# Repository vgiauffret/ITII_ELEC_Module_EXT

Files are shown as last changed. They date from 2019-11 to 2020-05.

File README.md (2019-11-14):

# ITII_ELEC_Module_EXT
Notre projet consiste à améliorer une ruche d’abeille en y ajoutant des capteurs pour permettre à un apiculteur d’obtenir différentes informations sur son ruché tel que la température, l’humidité et le poids de la ruche.

Toutes ces améliorations de la ruche ne doivent en aucun cas gêner l’apiculteur dans son travail et doivent permettre à la ruche de rester mobile. Le système doit être autonome.

Nous sommes en charges de créer le module externe de la Ruche. Le but du module externe de la ruche connecté est de gérer, d'enregistrer la visite de l'apiculteur et de transmettre les données relatives à l'entretien des ruches à une gateway. Le module devra fournir une IHM pour permettre à l'apiculteur d'interagir avec le système et de plusieurs capteurs permettant de récupérer les informations désirées.

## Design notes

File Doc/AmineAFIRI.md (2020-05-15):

Liste des taches
==
- Nom : AFIRI Amine
- Module : Module externe

% Accompli | Nom de la taches | Echeance | Notes
---------- | ---------------- | ---------- | --------------:
100 %  | Cahier charges | 08/11/2019 | Etablir le cahier des charges du module externe 
100 %  | Mise en place du répertoire Github | 08/11/2019 | Création du repository + ajout du cahier des charge + les fichiers taches
100 %  |Recherche| 29/11/2019 | Lecture de la Datasheet de l'ESP32 + Ecran LCD
100    |cablage FTDI232 et ESP32| 29/11/2019 | cablâge des modules pour compilation 
50 %   |Configuration de l'écran LCD| 29/11/2019 | code de test pour afficher des caractères à l'écran
50 %   |Recherche | 13/12/2019 | Recherche sur le ESP3266 + Ecran LCD SSD1306
80 %   |Configuration de l'écran LCD| 13/12/2019 | L'écran s'allume mais probleme de calibrage
100 %  |Reinstallation du noyau Linux| 17/01/2020 | Probleme d'ecran apres mauvaise manipulation
70 %   |Recherche | 17/01/2020 | Recherche sur le ESP3266 + Ecran LCD SSD1306
100 %  |Configuration de l'écran LCD| 17/01/2020 | L'écran s'allume est on peut afficher differentes chaines de caracteres
100 %  |Recherche| 20/01/2020 | Lecture de la Datasheet de du capteur de température DHT22
100 %  |cablage| 20/01/2020 | cablâge du capteur DHT22 pour test 
10 %   |Codage| 20/01/2020 | Elaboration d'un programme qui récupère les données du capteur DHT22
0 %  |Absence| 24/01/2020 | Injustifié (Pour raison personnelle)
0 %  |Absence| 07/02/2020 | Maladie
0 %  |Absence| 08/02/2020 | Maladie
100 %  |Codage| 14/02/2020 | Mise en marche d'un programme qui récupère les données du capteur DHT22
70 %  |Configuration de la balance| 14/02/2020 | Autocalibration de la balance sans intervention de l'utilisateur
70 %  |Configuration de la balance| 20/03/2020 | Autocalibration de la balance sans intervention de l'utilisateur
100 %  |Configuration de la balance | 17/04/2020 | Test écriture et lecture de l'EEPROM
70 %  |Configuration de la balance| 17/04/2020 | Autocalibration de la balance sans intervention de l'utilisateur + Enregistrement des données dans l'EEPROM
100 %  |Configuration de la balance | 22/04/2020 |  Autocalibration de la balance sans intervention de l'utilisateur + Enregistrement des données dans l'EEPROM
60 %  | Recherche Composants | 22/04/2020 | Choix et comparaisons des compossants chez Farnell et RS

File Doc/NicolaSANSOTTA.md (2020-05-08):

Liste des taches
==
- Nom : SANSOTTA Nicola
- Module : Module externe

% Accompli | Nom de la taches | Echeance | Notes
---------- | ---------------- | ---------- | --------------:
100 %  | Cahier charges | 08/11/2019 | Etablir le cahier des charges du modules externes 
100 %  | Diagramme de Gant | 08/11/2019 | Planification des tâches 
100 %  |cablage FTDI232 et ESP32| 29/11/2019 | cablâge des modules pour compilation 
50 %   |configuration de la balance| 29/11/2019 | code de test pour récupérer les valeurs depuis le module NAU7802
100 %  |configuration de la balance| 13/12/2019 | code de test pour récupérer les valeurs depuis le module NAU7802
probléme     |configuration de la balance| 13/12/2019 | Probléme de compilation depuis la plateforme Arduino vers l'ESP3266
25 %   |configuration de la balance| 13/12/2019 | Convertions des valeurs en unité de masse
35 %   |configuration de la balance| 10/01/2020 | Convertions des valeurs en unité de masse
5 %    |Implémentation de la carte| 10/01/2020 | Cablage NAU7802 seul
20 %    |Implémentation de la carte| 11/01/2020 | Cablage des 2 NAU7802 et des différents connecteurs sur Schematic
40 %    |Implémentation de la carte| 20/01/2020 | Cablage et test sur platine des 2 voyant lumineux
50 %    |Implémentation de la carte| 20/01/2020 | Cablage et test des 2 pont diviseur pour messurer la tension d'alimentation et de la baterie
55 %    |Implémentation de la carte| 20/01/2020 | Atribution des pins utilisée sur L'ESP32
65 %    |Implémentation de la carte| 24/01/2020 | Cablage du capteur de température DHT et de la LDR
modification    |Implémentation de la carte| 24/01/2020 | Changement de pin concernant la tension d'entrée du pont diviseur pour messurer la baterie
100 %    |Présentation module externe| 08/02/2020 | 
100 %    |Implémentation de la carte| 14/02/2020 | Finalisation des différents câblage sur le schematic
20 %    |Routgae PCB| 20/03/2020 | Début du routage de la carte module externe ESP_Rucher
100 %    |Routgae PCB| 17/04/2020 | Finalisation de la carte module externe ESP_Rucher
60 %    |Recherche Composants| 22/04/2020 | Choix et comparaisons des compossants chez Farnell et RS

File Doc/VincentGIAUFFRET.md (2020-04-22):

Liste des taches
==
- Nom : GIAUFFRET Vincent
- Module : Module externe

% Accompli | Nom de la taches | Echeance | Notes
---------- | ---------------- | ---------- | --------------:
100 %  |Cahier charges | 08/11/2019 | Etablir le cahier des charges du modules externes 
100 %  |Mise en place répertoire Github | 08/11/2019 | Création du repository + ajout du cahier des charge + les fichiers taches
10 %   |Recherche | 25/11/2019 | Recherche sur le ESP3266 + Ecran LCD SSD1306
100 %  |Cablage FTDI232 et ESP32| 29/11/2019 | cablâge des modules pour compilation 
50 %   |Configuration de l'écran LCD| 29/11/2019 | code de test pour afficher des caractères à l'écran
50 %   |Recherche | 13/12/2019 | Recherche sur le ESP3266 + Ecran LCD SSD1306
80 %   |Configuration de l'écran LCD| 13/12/2019 | L'écran s'allume mais probleme de calibrage
100 %  |Reinstallation du noyau Linux| 17/01/2020 | Probleme d'ecran apres mauvaise manipulation
70 %   |Recherche | 17/01/2020 | Recherche sur le ESP3266 + Ecran LCD SSD1306
100 %  |Configuration de l'écran LCD| 17/01/2020 | L'écran s'allume est on peut afficher differentes chaines de caracteres
100 %  |Mesure Batterie et Alimentation | 20/01/2020 | Pont diviseur pour la mesure de la batterie et de l'alimentation
100 %  |LED Red & Green | 20/01/2020 | Ajout des deux LED et code pour les alimenter
100 %  |Recherche | 17/01/2020 | Recherche sur le ESP3266 + Ecran LCD SSD1306
50 %   |Configuration de l'écran LCD| 20/01/2020 | Modification de l'I2C pour le controler
100 %  |Configuration du module LoRa| 24/01/2020 | Envoyer un message et lire les messages recu
100 %  |Configuration de l'écran LCD| 24/01/2020 | Modification de l'I2C pour le controler
100 %  |Configuration de la photoresistance| 24/01/2020 | Lire la valeur de la luminosité
100 %  |Présentation | 07/02/2020 | Powerpoint de présentation
100 %  |Présentation | 08/02/2020 | Présentation
5 %    |Assemblage Code | 14/02/2020 | Réveil du systéme avec appuie sur le bouton next
10 %   |Assemblage Code | 14/02/2020 | Défilement du menu avec le bouton next
25 %   |Assemblage Code | 14/02/2020 | Ajout du bouton validation
100 %  |Test Eeprom Code | 17/04/2020 | Ecrire et lire dans l'eeprom
30 %   |Balance Code | 17/04/2020 | Proceder au mesure de poids
100 %  |Balance Code | 22/04/2020 | Mesure de poid + ajout code a l'init de l'eeprom
25 %   |Assemblage Code | 22/02/2020 | Ajout du bouton validation

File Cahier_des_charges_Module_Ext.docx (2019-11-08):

Cahier des charges

Module externe ruche connectée

Le but du module externe de la ruche connecté est de gérer, d'enregistrer la visite de l'apiculteur et de transmettre les données relatives à l'entretien des ruches à une gateway. Le module devra fournir une IHM pour permettre à l'apiculteur d'interagir avec le système et de plusieurs capteurs permettant de récupérer les informations désirées.

Les exigences du système sont les suivantes :

1 : Mesurer l’hygrométrie grâce au capteur HDC1080

2 : Mesurer le poids de la ruche grâce à la balance NUA7802

3 : Relever la température de la jauge de contrainte

4 : Gérer les dérives du capteur de force en utilisant les capteurs hygrométriques et de température

5 : Mettre à jour les valeurs mesurées toutes les 15 minutes

6 : Récupérer les mesures sur l’ESP3266

7 : Pouvoir interagir avec l’afficheur via 2 boutons poussoir

8 : Afficher le menu sur l’afficheur LCD SSD1306 qui sera composé des actions suivantes :

- Visite
- Sleep
- Sirop 50/50
- Sirop 70/30
- Candy
- Mesure seule

9 : Afficher le déroulement du processus de visite sur l’afficheur LCD

10 : Transmettre une trame résumant les actions de la visite

11 : Utiliser le RFM95 pour transmettre les trames (LoRa)

Schéma récapitulatif du système :

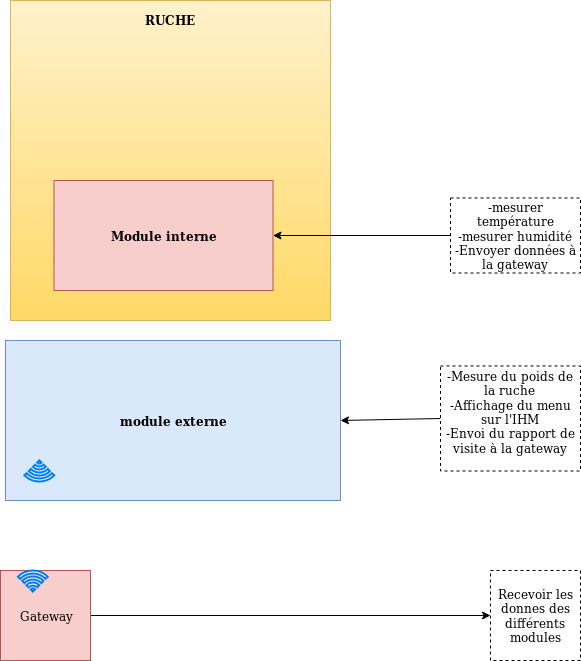
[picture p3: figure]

Le module externe est représenté par les éléments suivants :

Carte avec ESP32µc

+ Capteur Hygro (humidité)

+ 2 BP

Envoi donnée via RFM92

Communication LoRa

Balance NUA7802

Afficheur SSD1306

Annexe

Carte :

Intégration du µC ESP32

Insérer pont de Weaston qui permet d’intégrer la balance NUA7802 et de l’adapter en fonction du nombre de jauges 1, 2 ou 4 pour mesurer le poids de la ruche

1 jauge = 1 pont de Weaston avec 1 ADC NAU7802 (1 entrée utile)
2 jauges = 1 pont de Weaston avec 1 ADC NAU7802 (2 entrée utile)
4 jauges = 2 ponts de Weaston avec 2 ADC NAU7802 (2 entrée utile)

Insérer connecteur de l’afficheur SSD1306
Récupération du signal fournis par la balance avec CAN HX711 établir la connexion
Programmation du µC ESP32

Communication LoRa RFM95 :

Lecture des données (état des capteurs) de la part du système toutes les 15 min.

But => Transmettre une Trame qui contient valeur de masse et hygrométrie et action effectué par le manipulateur de la Ruche.

Gateway

TRAME

Code affichage

Carte vers ESP32

Afficheur

Afficheur :

Programmation avec la plateforme Arduino C++

Réveil du système avec BP et lecture des données (état des capteur)

Gestion du Menu (Sélection Visite ou Rien de la part du propriétaire de la Ruche)

Si Visite sélectionné alors enregistrement dans la table Viste (Envoie d’un TRAME)

Puis déroulement du processus :

But => Afficher la gestion des actions sur l’afficheur SSD1306 et validé que l’action est bien effectuée

Etape 1 : Mesure masse + Envoi donnée dans Trame vers Gateway + Afficher sur l’afficheur

Etape 2 : Accusé de réception

Etape 3 : Sleep pendant 15 ou 30 min à définir

Etape 4 : Afficher Sirop 50 / 50

Etape 5 : Validation Sirop 50 / 50

Etape 6 : Nouvelle mesure de masse (calcul de la différence pour obtenir la masse de sirop) + Envoi donnée dans Trame vers Gateway + Afficher sur l’afficheur

Nicola Sansotta Projet Electronique Ruche Malik Bedoui Vincent Giaufret Amine Afiri

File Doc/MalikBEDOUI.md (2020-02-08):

Liste des taches
==
- Nom : BEDOUI Malik 
- Module : Module externe

% Accompli | Nom de la taches | Echeance | Notes
---------- | ---------------- | ---------- | --------------:
100 %  | Cahier charges | 08/11/2019 | Etablir le cahier des charges du modules externes 
100 %   | Diagramme de Gant | 08/11/2019 | Planification des tâches 
100 %   |cablage FTDI232 et ESP32| 29/11/2019 | cablâge des modules pour compilation 
50 %   |configuration de la balance| 29/11/2019 | code de test pour récupérer les valeurs depuis le module NAU7802
50%    |Configuration de la balance| 13/12/2019 | problème de compilation sur l'esp ce qui nous a retardé
60%    |Configuration de la balance| 10/01/2020 | détermination de l'équation permettant d'avoir une valeur correspondant à un poid en kg.
70%    |Configuration de la balance| 17/01/2020 | autocalibration de la balance sans intervention de l'utilisateur.
70%    |Configuration de la balance| 20/01/2020 | Travail sur balance + cablage module lora.
70%    |Configuration de la balance + Lora| 17/01/2020 | autocalibration de la balance sans intervention de l'utilisateur.
70%    |Module Lora| 17/01/2020 | Envoi et reception de message avec Lora et affichage des bytes reçues sur LCD
100%    |Présentation module externe| 08/02/2020 |

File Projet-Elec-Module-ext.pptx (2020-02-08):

## Projet Electronique Ruche Connectée

Module Externe
Afiri / Bedoui / Giauffret / Sansotta

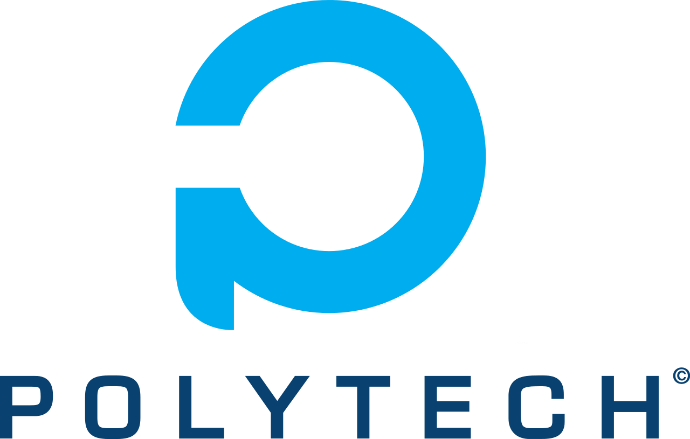
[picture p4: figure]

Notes: Vincent

## Contexte

Actuellement
Des améliorations en vue
Un projet commun avec toute la classe
Le module externe

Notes: Vincent

Depuis 2017 le projet de ruches connectées est lancé

Et notre objectif est d’ajouter des fonctionnalités pour améliorer et faciliter sa

S’interfacer avec les autres groupes, pour réussir a échanger des informations. Cette présentation sera même utile a connaitre les besoin de chaque groupe concernant les

Dans le cadre de la gestion de la ruche, le module externe permet de suivre et d’enregistrer l’état global de la ruche (température,hygrométrie,poids)

## Sommaire

- Vue d’ensemble Module Externe
- Mesures interne
- Communication
- IHM
- Autres fonctionnalités
- Prototypage carte module externe
- Implémentation carte module externe

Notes: Sansotta

## Vue d’ensemble Module Externe

Balance NUA7802

Capteur hygrométrique et de température

Capteur Luminosité

Carte avec ESP32µc

Envoi de données via RFM95
Communication LoRa

Afficheur SSD1306

LED

Boutons capacitifs

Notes: Sansotta

## Mesures internes

Balance
Luminosité
Température
Hygrométrie

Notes: Malik

Balance : vérifier poids du sirop injecté
système d’antivol
compter nombre d’abeille

Luminosité pour réduire le nombre de données envoyé durant la nuit

Température : palier les dérives du capteur de force de la balance(pas sûr qu’on va l’utiiliser)

Hygrométrie pour conservation du miel

## Communication

Réseau LoRa
Envoi des mesures internes

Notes: Malik

## IHM

Interface Homme Machine
Afficheur SSD1306
2 Voyants lumineux
2 boutons capacitifs

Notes: Vincent

## Autres fonctionnalités

Batterie
Alimentation

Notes: Vincent

## Prototypage carte module externe

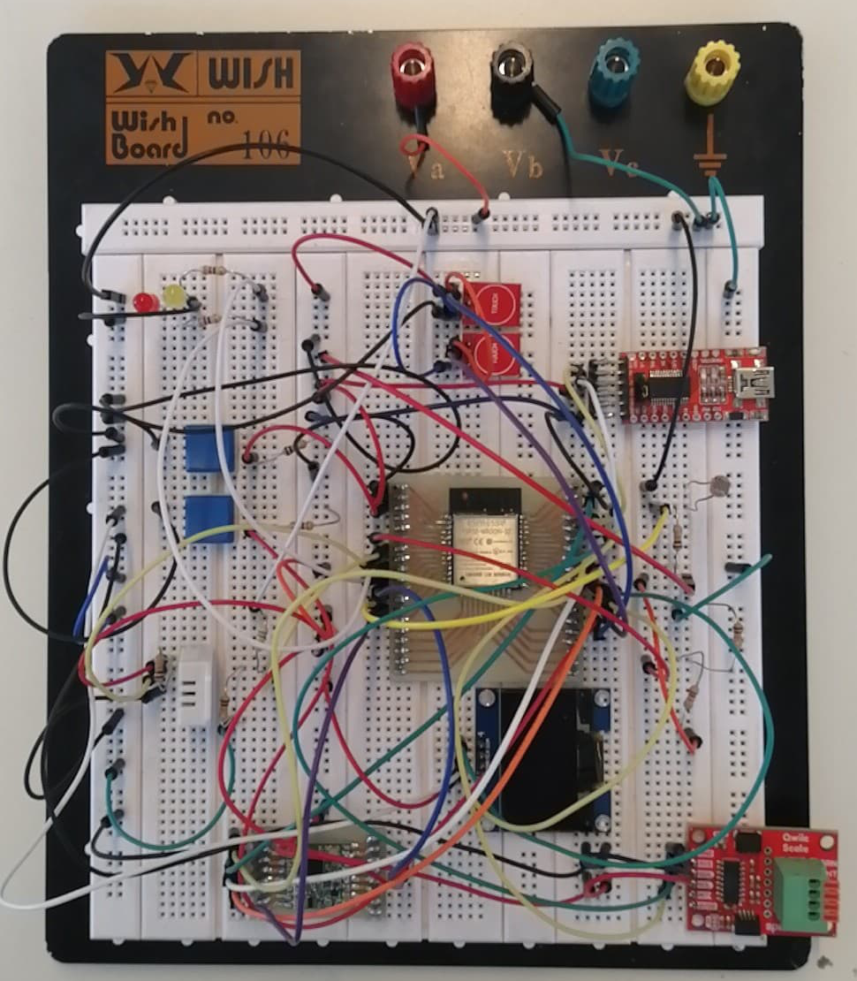
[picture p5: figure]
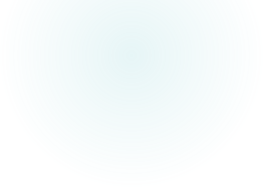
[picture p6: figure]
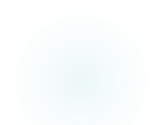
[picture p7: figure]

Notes: Sansotta

## Implémentation

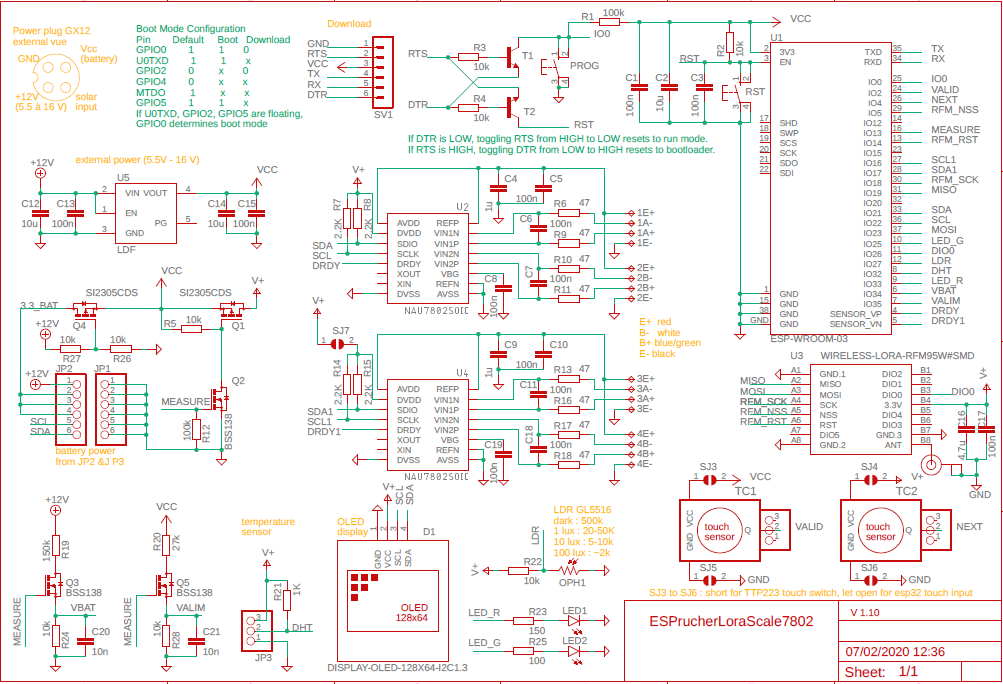
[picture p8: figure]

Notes: Sansotta

## Partage du code

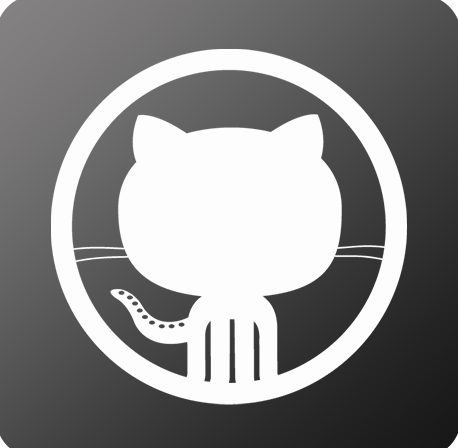
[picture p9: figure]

- Github
- Tableau des tâches et progression

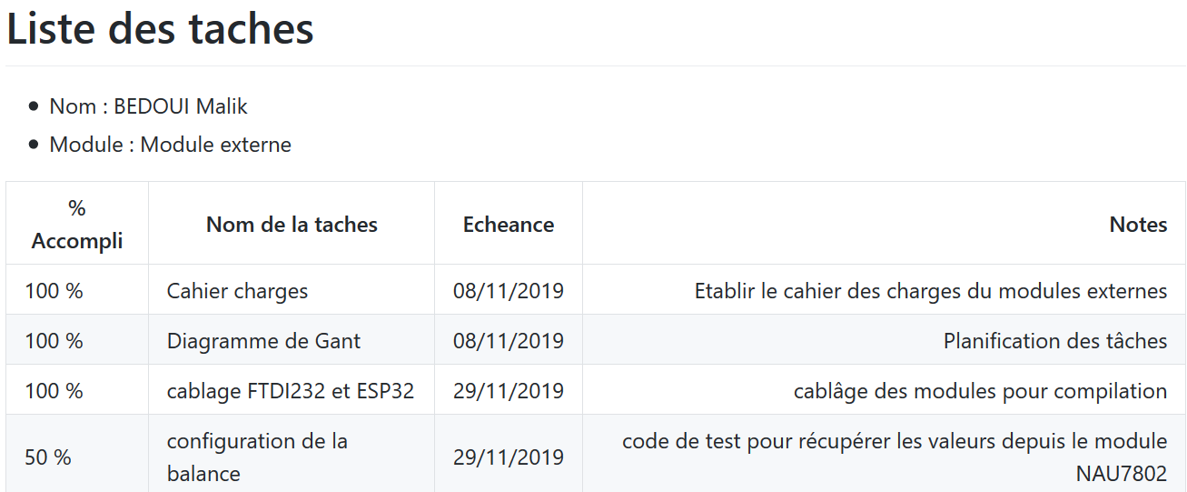
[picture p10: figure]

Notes: Malik

## Conclusion

Tâches | Accomplissement | Commentaires
Mesure de l’hygrométrie | ✔
Mesure de la température | ✔
Mise en place de l’IHM | ✔
Envoi de la trame en LoRa | ✔
Mesure de la luminosité | ✔
Alignement avec les autres groupes | X | Mettre en place un protocole pour la trame à envoyer
Assemblage de toutes les fonctionnalités | X | Intégration de toutes les fonctionnalités dans le programme final
Réalisation de la carte | X | Design du PCB à réaliser
Mesure du poids | X | En cours

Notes: Malik

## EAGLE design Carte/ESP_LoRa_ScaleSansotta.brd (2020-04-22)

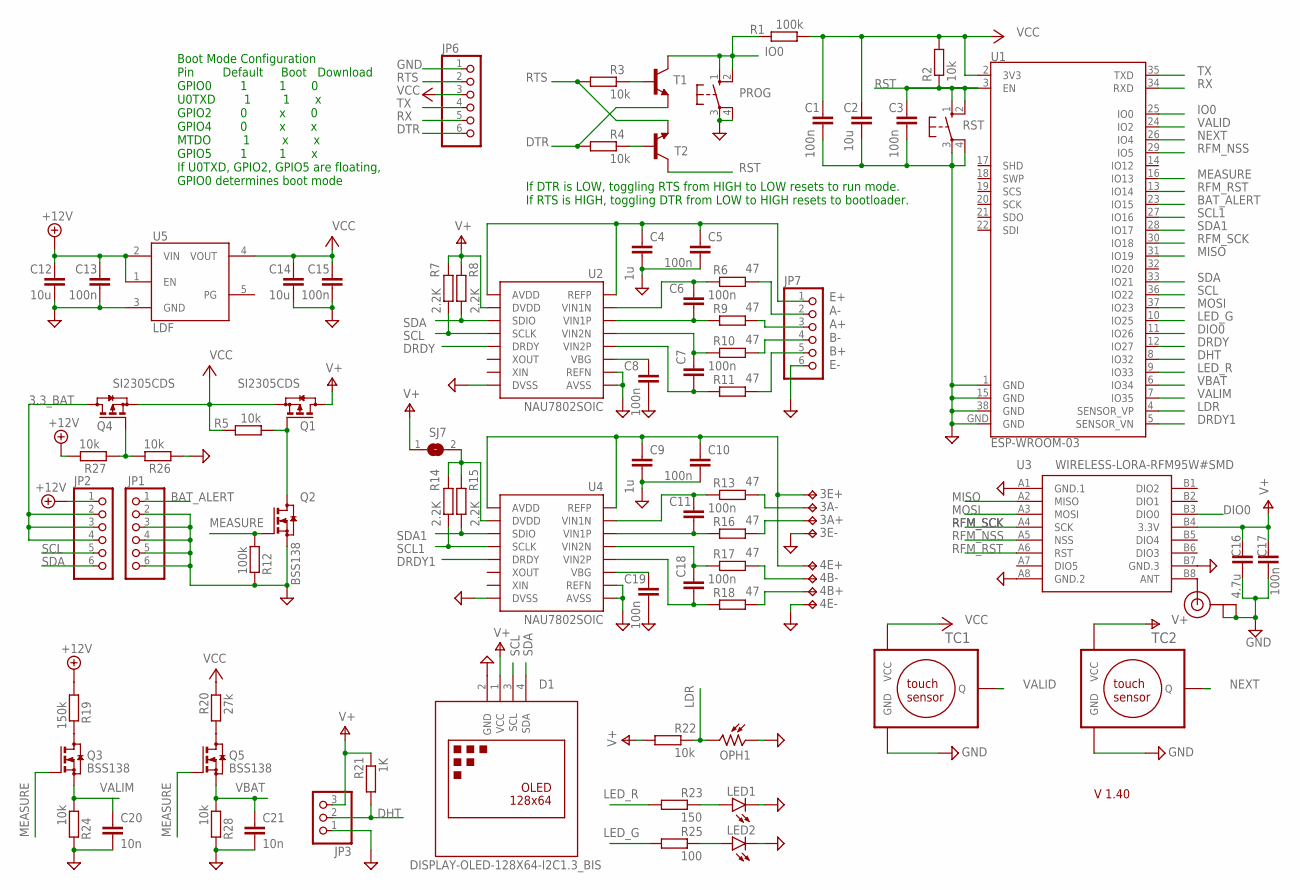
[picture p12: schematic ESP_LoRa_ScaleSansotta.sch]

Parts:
3A+, 3A-, 3E+, 3E-, 4B+, 4B-, 4E+, 4E-: TPTP17SQ; TP17SQ
C1, C3, C5, C6, C7, C8, C10, C11, C13, C15, C17, C18, C19: 100n; C1206
C2, C12, C14: 10u; C1210
C4, C9: 1u; C1210
C16: 4.7u; C1210
C20, C21: 10n; C1206
D1: DISPLAY-OLED-128X64-I2C1.3_BIS; DISPLAY-OLED-128X64-1.3-I2C_BIS
J1: U.FL
JP1, JP2, JP6, JP7: PINHD-1X6; 1X06
JP3: PINHD-1X3; 1X03
LED1, LED2: LEDSMT1206; 1206
OPH1: VT93N2; VT900
PROG: 10-XX; B3F-10XX
Q1, Q4: SI2305CDS; SOT23
Q2, Q3, Q5: BSS138; SOT23
R1, R12: 100k; R1206
R2, R3, R4, R5, R22, R24, R26, R27, R28: 10k; R1206
R6, R9, R10, R11, R13, R16, R17, R18: 47; R1206
R7, R8, R14, R15: 2.2K; R1206
R19: 150k; R1206
R20: 27k; R1206
R21: 1K; R1206
R23: 150; R1206
R25: 100; R1206
RST: 10-XX; B3F-10XX
SJ7: SJ
T1, T2: MMBT2222ALT1-NPN-SOT23-BEC; SOT23-BEC
TC1, TC2: TTP223R_H; TTP233RED_H
U1: ESP-WROOM-03
U2, U4: NAU7802SOIC; SO16
U3: WIRELESS-LORA-RFM95W#SMD
U5: LDF3.3; PPAK

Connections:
3.3_BAT: JP2.2, JP2.3, JP2.4, Q4.3 (D)
+12V: C12.1, C13.1, JP2.1, R19.1, R27.2, U5.1 (EN), U5.2 (VIN)
BAT_ALERT: JP1.1, U1.23 (IO15)
DHT: JP3.2, R21.1, U1.8 (IO32)
DIO0: U1.11 (IO26), U3.B3 (DIO0)
DRDY: U1.12 (IO27), U2.12 (DRDY)
DRDY1: U1.5 (SENSOR_VN), U4.12 (DRDY)
DTR: JP6.6, R4.1, T1.E
GND: 3E-.TP, 4E-.TP, C1.2, C2.2, C3.2, C4.2, C5.2, C8.2, C9.2, C10.2, C12.2, C13.2, C14.2, C15.2, C16.2, C17.2, C19.2, C20.2, C21.2, D1.2 (GND), J1.1 (GND), J1.2 (GND), JP1.2, JP1.3, JP1.4, JP1.5, JP1.6, JP3.1, JP6.1, JP7.6, LED1.C, LED2.C, OPH1.1, PROG.3, PROG.4 (P1), Q2.2 (S), R12.2, R24.2, R26.1, R28.2, RST.3, RST.4 (P1), TC1.P$3 (GND), TC2.P$3 (GND), U1.1 (GND), U1.15 (GND), U1.38 (GND), U1.GND, U2.7 (REFN), U2.8 (AVSS), U2.9 (DVSS), U3.A1 (GND.1), U3.A8 (GND.2), U3.B7 (GND.3), U4.7 (REFN), U4.8 (AVSS), U4.9 (DVSS), U5.3 (GND)
IO0: PROG.1 (S), PROG.2 (S1), R1.2, T1.C, U1.25 (IO0)
LDR: OPH1.2, R22.2, U1.4 (SENSOR_VP)
LED_G: R25.1, U1.10 (IO25)
LED_R: R23.1, U1.9 (IO33)
MEASURE: Q2.1 (G), Q3.1 (G), Q5.1 (G), R12.1, U1.16 (IO13)
MISO: U1.31 (IO19), U3.A2 (MISO)
MOSI: U1.37 (IO23), U3.A3 (MOSI)
unnamed: Q1.1 (G), Q2.3 (D), R5.1
unnamed: Q3.3 (D), R19.2
unnamed: J1.3 (SIGNAL), U3.B8 (ANT)
unnamed: R14.2, R15.2, SJ7.2, U4.15 (DVDD)
unnamed: Q5.3 (D), R20.1
unnamed: LED1.A, R23.2
unnamed: LED2.A, R25.2
unnamed: R3.2, T1.B
unnamed: JP7.2, R6.2
unnamed: R4.2, T2.B
unnamed: C8.1, U2.6 (VBG)
unnamed: C19.1, U4.6 (VBG)
unnamed: C11.2, R16.1, U4.3 (VIN1P)
unnamed: C11.1, R13.1, U4.2 (VIN1N)
unnamed: C6.2, R9.1, U2.3 (VIN1P)
unnamed: C6.1, R6.1, U2.2 (VIN1N)
unnamed: C7.1, R10.1, U2.4 (VIN2N)
unnamed: C7.2, R11.1, U2.5 (VIN2P)
unnamed: JP7.3, R9.2
unnamed: JP7.5, R11.2
unnamed: JP7.4, R10.2
unnamed: C18.1, R17.1, U4.4 (VIN2N)
unnamed: C18.2, R18.1, U4.5 (VIN2P)
unnamed: 4B+.TP, R18.2
unnamed: 4B-.TP, R17.2
unnamed: 3E+.TP, 4E+.TP, C9.1, C10.1, U4.1 (REFP), U4.16 (AVDD)
unnamed: 3A-.TP, R13.2
unnamed: 3A+.TP, R16.2
unnamed: C4.1, C5.1, JP7.1, U2.1 (REFP), U2.16 (AVDD)
unnamed: Q4.1 (G), R26.2, R27.1
NEXT: TC2.P$2 (Q), U1.26 (IO4)
RFM_NSS: U1.29 (IO5), U3.A5 (NSS)
RFM_RST: U1.13 (IO14), U3.A6 (RST)
RFM_SCK: U1.30 (IO18), U3.A4 (SCK)
RST: C3.1, R2.1, RST.1 (S), RST.2 (S1), T2.C, U1.3 (EN)
RTS: JP6.2, R3.1, T2.E
RX: JP6.5, U1.34 (RXD)
SCL: D1.3 (SCL), JP2.5, R7.1, U1.36 (IO22), U2.13 (SCLK)
SCL1: R14.1, U1.27 (IO16), U4.13 (SCLK)
SDA: D1.4 (SDA), JP2.6, R8.1, U1.33 (IO21), U2.14 (SDIO)
SDA1: R15.1, U1.28 (IO17), U4.14 (SDIO)
TX: JP6.4, U1.35 (TXD)
V+: C16.1, C17.1, D1.1 (VCC), JP3.3, Q1.3 (D), R7.2, R8.2, R21.2, R22.1, SJ7.1, TC2.P$1 (VCC), U2.15 (DVDD), U3.B4 (3.3V)
VALID: TC1.P$2 (Q), U1.24 (IO2)
VALIM: C20.1, Q3.2 (S), R24.1, U1.7 (IO35)
VBAT: C21.1, Q5.2 (S), R28.1, U1.6 (IO34)
VCC: C1.1, C2.1, C14.1, C15.1, JP6.3, Q1.2 (S), Q4.2 (S), R1.1, R2.2, R5.2, R20.2, TC1.P$1 (VCC), U1.2 (3V3), U5.4 (VOUT)

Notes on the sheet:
If DTR is LOW, toggling RTS from HIGH to LOW resets to run mode. If RTS is HIGH, toggling DTR from LOW to HIGH resets to bootloader.
Boot Mode Configuration Pin Default Boot Download GPIO0 1 1 0 U0TXD 1 1 x GPIO2 0 x 0 GPIO4 0 x x MTDO 1 x x GPIO5 1 1 x If U0TXD, GPIO2, GPIO5 are floating, GPIO0 determines boot mode
V 1.40
E+ A- A+ B- B+ E-

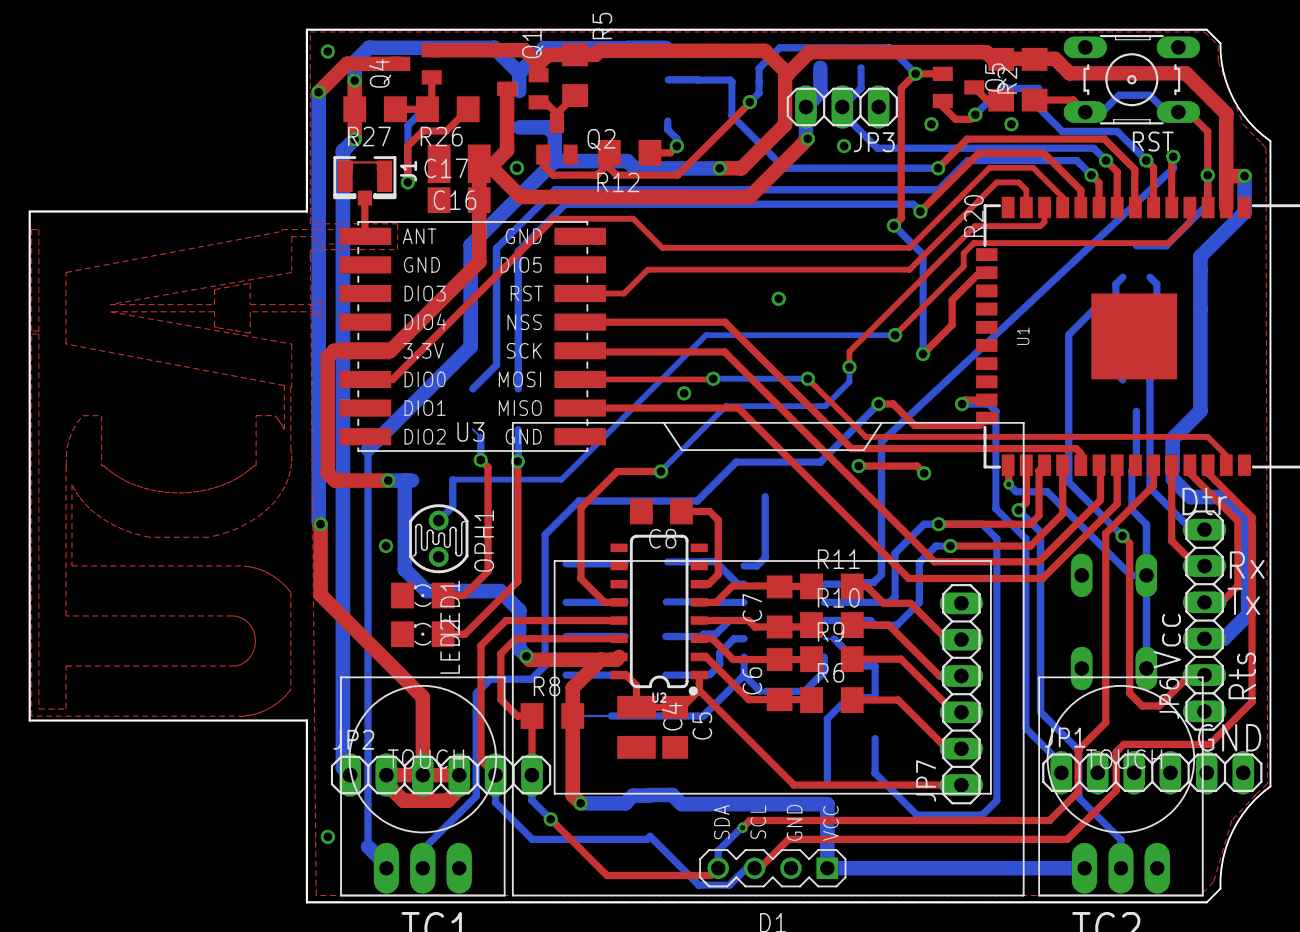
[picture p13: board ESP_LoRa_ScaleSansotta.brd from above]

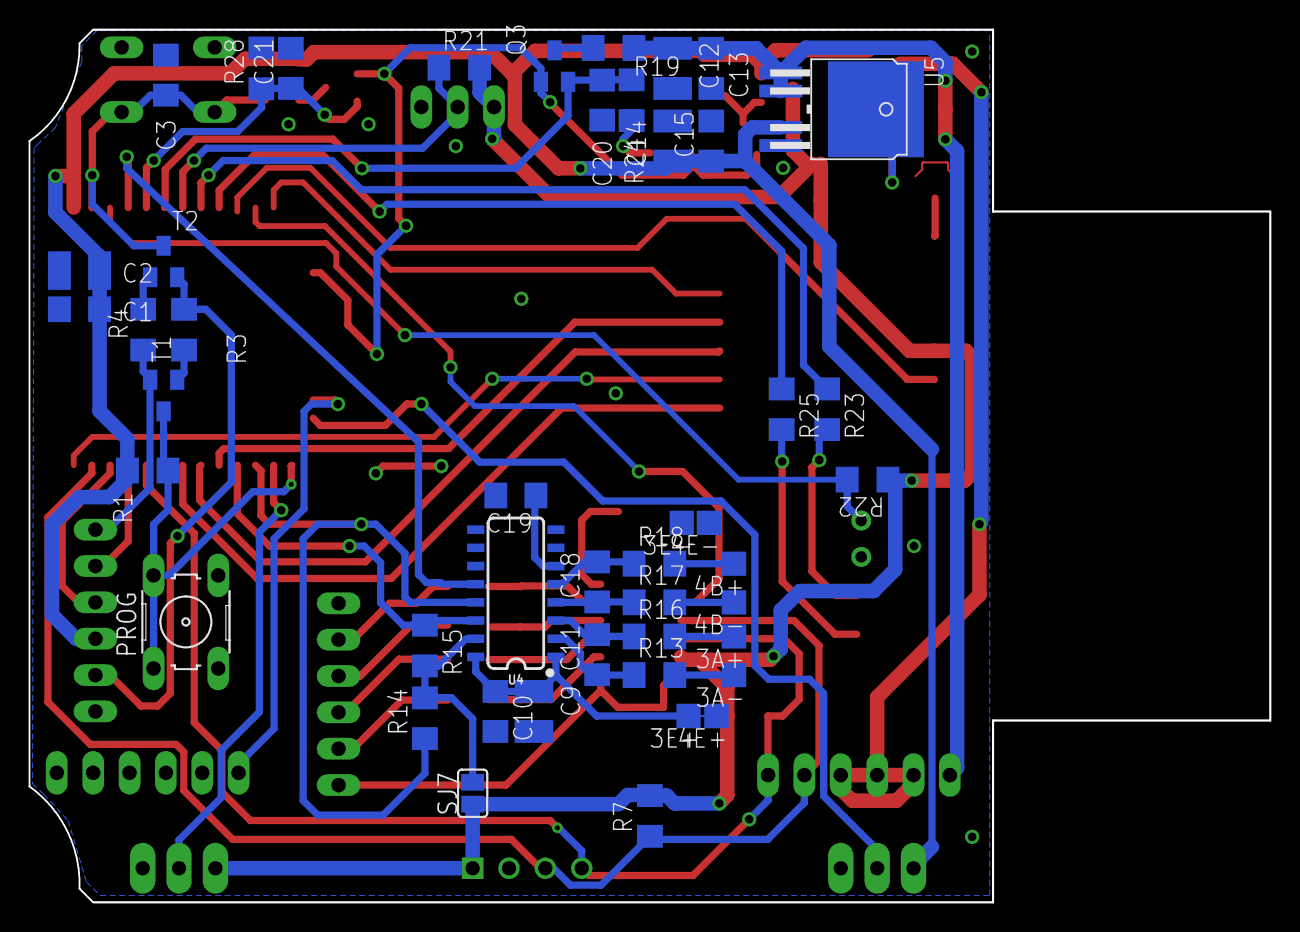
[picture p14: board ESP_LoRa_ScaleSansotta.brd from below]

Board: 2 copper layers, 86.7 x 61.0 mm, 84 parts (46 on the bottom side), 63 nets.

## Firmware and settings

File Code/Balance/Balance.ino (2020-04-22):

#include <Wire.h>
#include <EEPROM.h> //Needed to record user settings
#include "SparkFun_Qwiic_Scale_NAU7802_Arduino_Library.h" // Click here to get the library: http://librarymanager/All#SparkFun_NAU8702

NAU7802 myScale; //Create instance of the NAU7802 class

//EEPROM locations to store 4-byte variables
#define LOCATION_CALIBRATION_FACTOR 0 //Float, requires 4 bytes of EEPROM
#define LOCATION_ZERO_OFFSET 10 //Must be more than 4 away from previous spot. Long, requires 4 bytes of EEPROM
#define EEPROM_SIZE 128
#define LOCATION_CODE 15
#define CODE 123456789

bool settingsDetected = false; //Used to prompt user to calibrate their scale
int flag =0;

int read_eeprom_code(void);
void recordSystemSettings(void);
void readSystemSettings(void);
void calibrateScale(void);

void setup()
{
  Serial.begin(9600);
  Wire.begin();
  Wire.setClock(400000); //Qwiic Scale is capable of running at 400kHz if desired

  if (!EEPROM.begin(EEPROM_SIZE)) 
  {
    Serial.println("Failed to initialise EEPROM");
  }
  flag = read_eeprom_code();
  if (myScale.begin() == false)
  {
    Serial.println("Scale not detected. Please check wiring. Freezing...");
    while (1);
  }
  Serial.println("Scale detected!");

  readSystemSettings(); //Load zeroOffset and calibrationFactor from EEPROM

  myScale.setSampleRate(NAU7802_SPS_320); //Increase to max sample rate
  myScale.calibrateAFE(); //Re-cal analog front end when we change gain, sample rate, or channel 

  Serial.print("Zero offset: ");
  Serial.println(myScale.getZeroOffset());
  Serial.print("Calibration factor: ");
  Serial.println(myScale.getCalibrationFactor());

  if (flag != 123456789)
  {
  settingsDetected = false;
  }
}

void loop()
{   
  if (myScale.available() == true)
  {
    float currentWeight = myScale.getWeight(false,64);

    Serial.print("\tWeight: ");
    Serial.print(myScale.getWeight(false,64), 3); //Print 3 decimal places

    if(settingsDetected == false) //Tester le code dans l'eeprom
    {
      Serial.print("\tScale not calibrated.");
      calibrateScale();
    }
    Serial.println();
  }
}

int read_eeprom_code() 
{
  int result = 0;
  Serial.println("Lecture de l'eeprom !");
  EEPROM.get(LOCATION_CODE, result);
  Serial.println(result);
  return result;
}

//Gives user the ability to set a known weight on the scale and calculate a calibration factor
void calibrateScale(void)
{
  Serial.println();
  Serial.println();
  Serial.println(F("Scale calibration"));

  Serial.println(F("Ne poser aucun poid sur la balance. Appuyer sur une touche lorsque vous etes pret."));
  while (Serial.available()) Serial.read(); //Clear anything in RX buffer
  while (Serial.available() == 0) delay(10); //Wait for user to press key

  myScale.calculateZeroOffset(128); //Zero or Tare the scale. Average over 64 readings.
  Serial.print(F("New zero offset: "));
  Serial.println(myScale.getZeroOffset());

  Serial.println(F("Placer un poid connu sur la balance. Appuyer sur une touche lorsque le poid est positionné et stable."));
  while (Serial.available()) Serial.read(); //Clear anything in RX buffer
  while (Serial.available() == 0) delay(10); //Wait for user to press key

  Serial.print(F("Entrez la valuer du poid, sans unités, Qui se trouve sur la balance :"));
  while (Serial.available()) Serial.read(); //Clear anything in RX buffer
  while (Serial.available() == 0) delay(10); //Wait for user to press key

  //Read user input
  float weightOnScale = Serial.parseFloat();
  Serial.println();

  myScale.calculateCalibrationFactor(weightOnScale, 128); //Tell the library how much weight is currently on it
 
  settingsDetected = true;

  recordSystemSettings(); //Commit these values to EEPROM

  readSystemSettings(); //Load zeroOffset and calibrationFactor from EEPROM

  Serial.print("Zero offset: ");
  Serial.println(myScale.getZeroOffset());
  Serial.print("Calibration factor: ");
  Serial.println(myScale.getCalibrationFactor());
}

//Record the current system settings to EEPROM
void recordSystemSettings(void)
{
  //Get various values from the library and commit them to NVM
  EEPROM.put(LOCATION_CALIBRATION_FACTOR, myScale.getCalibrationFactor());
  EEPROM.put(LOCATION_ZERO_OFFSET, myScale.getZeroOffset());
  EEPROM.put(LOCATION_CODE, CODE);
  EEPROM.commit();
  Serial.println("On vient d'écrire dans l'Eeprom !");
}

//Reads the current system settings from EEPROM
//If anything looks weird, reset setting to default value
void readSystemSettings(void)
{
  float settingCalibrationFactor=0; //Value used to convert the load cell reading to lbs or kg
  long settingZeroOffset=0; //Zero value that is found when scale is tared
  
  read_eeprom_code(); //Lecture du Code dans l'eeprom

  //Look up the calibration factor
  EEPROM.get(LOCATION_CALIBRATION_FACTOR, settingCalibrationFactor);
  if (settingCalibrationFactor == 0xFFFFFFFF)
  {
    settingCalibrationFactor = 0; //Default to 0
    EEPROM.put(LOCATION_CALIBRATION_FACTOR, settingCalibrationFactor);
  }

  //Look up the zero tare point
  EEPROM.get(LOCATION_ZERO_OFFSET, settingZeroOffset);
  if (settingZeroOffset == 0xFFFFFFFF)
  {
    settingZeroOffset = 1000L; //Default to 1000 so we don't get inf
    EEPROM.put(LOCATION_ZERO_OFFSET, settingZeroOffset);
  }


  //Pass these values to the library
  myScale.setCalibrationFactor(settingCalibrationFactor);
  myScale.setZeroOffset(settingZeroOffset);

  settingsDetected = true; //Assume for the moment that there are good cal values
  if (settingCalibrationFactor < 0.1 || settingZeroOffset == 1000)
  {
    settingsDetected = false; //Defaults detected. Prompt user to cal scale.
  }
}

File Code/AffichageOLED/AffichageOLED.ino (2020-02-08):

  /**
 * The MIT License (MIT)
 *
 * Copyright (c) 2018 by ThingPulse, Daniel Eichhorn
 * Copyright (c) 2018 by Fabrice Weinberg
 *
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
 * ThingPulse invests considerable time and money to develop these open source libraries.
 * Please support us by buying our products (and not the clones) from
 * https://thingpulse.com
 *
 */
#define I2C_SDA 17 //IO17
#define I2C_SCL 16 //IO16 

// Include the correct display library
// For a connection via I2C using the Arduino Wire include:
#include <Wire.h>               // Only needed for Arduino 1.6.5 and earlier
#include "SH1106Wire.h"   // legacy: #include "SH1106.h"


// Optionally include custom images
#include "images.h"
// Initialize the OLED display using Arduino Wire:
SH1106Wire display(0x3c, I2C_SDA, I2C_SCL);     // ADDRESS, SDA, SCL


#define DEMO_DURATION 3000
typedef void (*Demo)(void);

int demoMode = 0;
int counter = 1;

void setup() {
  Serial.begin(115200);
  Serial.println();
  Serial.println();


  // Initialising the UI will init the display too.
  display.init();

  display.flipScreenVertically();
  display.setFont(ArialMT_Plain_10);

}

void Accueil() {
    display.setTextAlignment(TEXT_ALIGN_LEFT);
    display.setFont(ArialMT_Plain_16);
    display.drawStringMaxWidth(10, 10, 128,"Projet Ruche Module Externe");
}

void MenuDefile() {
    char* Menu[]={"Visite","Sleep","Sirop   50/50","Sirop   70/30","Candy", "Mesure seule"};
    int indice;
    for(indice=0;indice<6;indice++)
    {
    // clear the display
    display.clear();
    display.setFont(ArialMT_Plain_24);
    display.setTextAlignment(TEXT_ALIGN_LEFT);
    display.drawStringMaxWidth(33, 10, 128,Menu[indice]);
    // write the buffer to the display
    display.display();
    delay(2000);
    }
}


void drawProgressBarDemo() {
  int progress = (counter / 5) % 100;
  // draw the progress bar
  display.drawProgressBar(0, 32, 120, 10, progress);

  // draw the percentage as String
  display.setTextAlignment(TEXT_ALIGN_CENTER);
  display.drawString(64, 0, String(progress) + "%");
}

void drawImageDemo() {
    // see http://blog.squix.org/2015/05/esp8266-nodemcu-how-to-create-xbm.html
    // on how to create xbm files
    display.drawXbm(34, 14, WiFi_Logo_width, WiFi_Logo_height, WiFi_Logo_bits);
}

//Demo demos[] = {drawFontFaceDemo, drawTextFlowDemo, drawProgressBarDemo, drawImageDemo};
Demo demos[] = {Accueil,drawImageDemo,MenuDefile,drawProgressBarDemo};

int demoLength = (sizeof(demos) / sizeof(Demo));
long timeSinceLastModeSwitch = 0;

void loop() {
  // clear the display
  display.clear();
  
    //demos[MenuDefile]();
  


    // draw the current demo method
  demos[demoMode]();



  //display.setTextAlignment(TEXT_ALIGN_RIGHT);
  //display.drawString(10, 128, String(millis()));
  // write the buffer to the display
  display.display();

  if (millis() - timeSinceLastModeSwitch > DEMO_DURATION) {
    demoMode = (demoMode + 1)  % demoLength;
    timeSinceLastModeSwitch = millis();
  }
  counter++;
  delay(10);
}

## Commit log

2019-11-08 Add Cahier des charges
    Fichier word qui contient le cahier des charges du module externe de la ruche connectée
2019-11-08 Ajout dossier taches de chaque eleves
    [Giauffret_Taches.ods]
2019-11-08 Bedoui_taches
    résumé des tâches effectués à chaque séance
    [Bedoui_Taches.ods]
2019-11-08 Ajout planning
    [Planing-Module-EXT.xlsx]
2020-01-20 Inventaire PInOut
    [InventairePinOUT.ods]
2020-02-08 Tableau d’assignation des Pins de l'ESP32
    [InventairePinOUT.ods]
2020-04-17 Create PCB

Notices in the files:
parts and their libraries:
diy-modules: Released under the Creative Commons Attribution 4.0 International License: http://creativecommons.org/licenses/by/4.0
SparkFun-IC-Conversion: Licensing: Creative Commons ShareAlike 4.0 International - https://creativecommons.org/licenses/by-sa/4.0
